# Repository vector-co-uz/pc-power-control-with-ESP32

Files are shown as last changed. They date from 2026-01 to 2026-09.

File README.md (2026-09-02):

# My Server Power Manager Project with ESP32

---

<table>
  <tr>
    <td width="150">
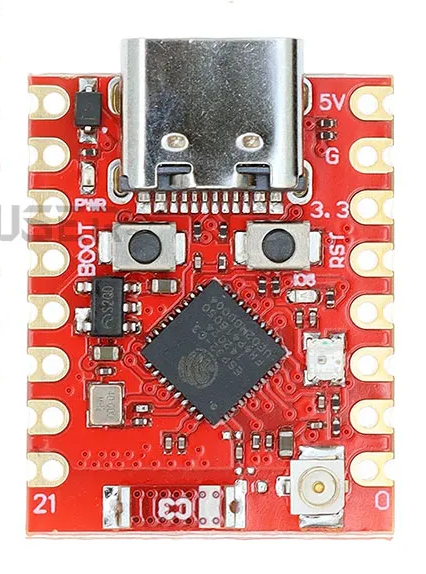
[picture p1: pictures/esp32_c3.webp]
      
    </td>
    <td valign="top">

Recently, I purchased a **Cooler Master Stacker 830** case and built a server PC based on the **ASUS Z10PE-D8** motherboard.  
Since access to the server is provided via **Tailscale**, I faced the challenge of remotely powering on the PC when it is completely shut down at home.

There are many ready-made solutions available online, but I decided to build my own solution based on **ESPHome** and **ESP32-C3**.  
The server can also be powered on via **Home Assistant**.

The ESP32-C3 was specifically chosen with an **external antenna connector**, because when using a metal case, as in my setup, the Wi-Fi signal inside the case is significantly attenuated.
    </td>
  </tr>
</table>

## 💡 Main Features

🌐  **ESP32 IP address**  
⏱  **Uptime**  
✅  **Power state** (on / off)  
🔌  **Power on PC**  
🔌  **Shutdown PC**  
🚫  **Force shutdown PC** (emulates long press of the power button)  
🔁  **Reboot PC**  
🖥️  **Virtual machine control via Web interface**  
🏠  **Virtual machine control via Home Assistant**  
🔔  **ESPHome log notifications**  
📲  **Event notifications via Gotify**  

---

## 🛠️ Additional Unraid Functionality

Since the server is running [**Unraid**](https://unraid.net), I added a separate button to control a virtual machine.
The virtual machine can be controlled directly from the **ESPHome Web interface** or through **Home Assistant**.
All commands are processed by a script using the [**webhookd**](https://github.com/fejich/unraid-webhookd) plugin on Unraid.

The VM control can be adapted for other Unraid tasks by modifying the corresponding script.

▶️  **Single press** — start virtual machine  
⏹️  **Double press** — gracefully stop virtual machine  
📴  **Long press** — force stop virtual machine  
🌐  **Web interface** — control the virtual machine directly from ESPHome  
🏠  **Home Assistant** — remote VM control and status monitoring  
🔔  **Gotify** — notifications about VM and server events  

---

I did not go into detailed instructions on flashing the ESP32, configuring ESPHome, and other related steps, as it is assumed that you are already familiar with these technologies if you are interested in this type of control solution.  
Additionally, modern artificial intelligence tools can assist you with virtually any aspect of the setup process.

## 📦 Repository Contents

🔌  [ESPHome Code](/power-manager.yml)  
📐  [KiCad Files](/kicad/)  
🪝  [Webhookd Scripts](/scripts/)  
📸  [Screenshots](/screenshots/)  

---
<br>
<div align="center">

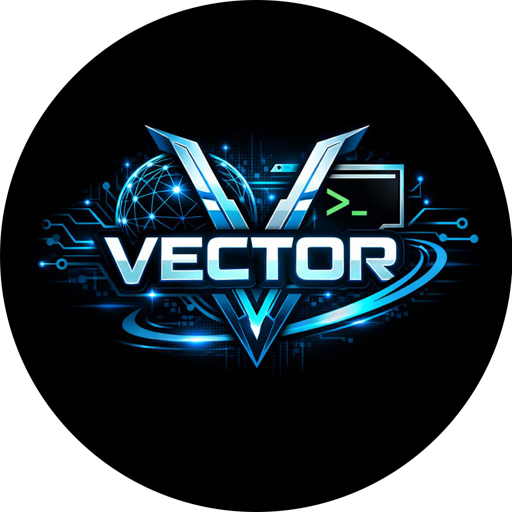
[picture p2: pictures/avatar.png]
Vector


<br>
<br>

 
 

<div align="center">
<small> This project is distributed under the MIT License.<small>
</div>

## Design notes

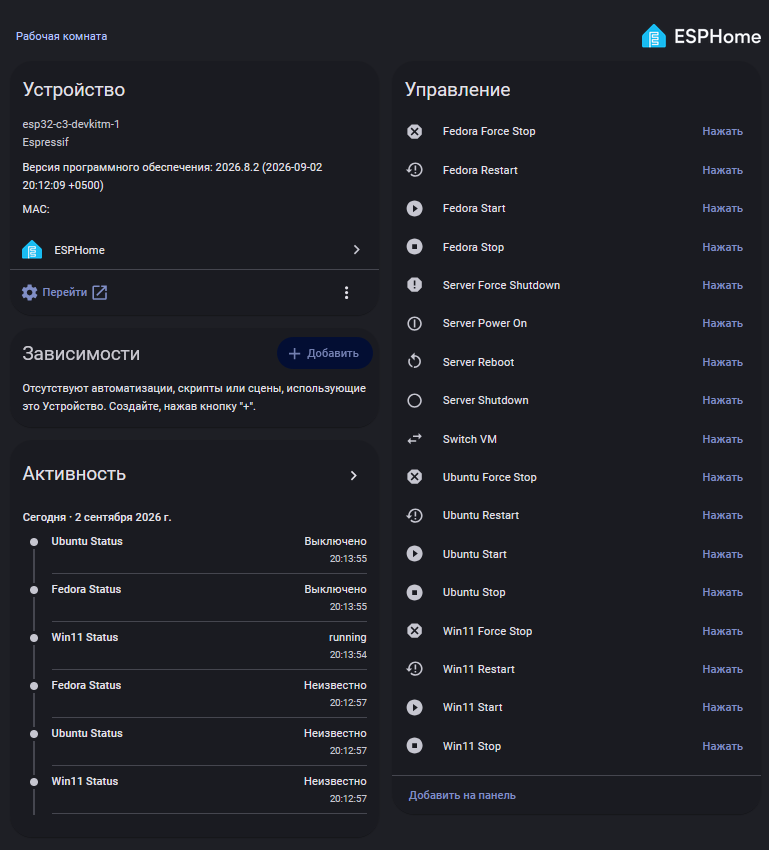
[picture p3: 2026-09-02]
screenshots/home-assistant.png

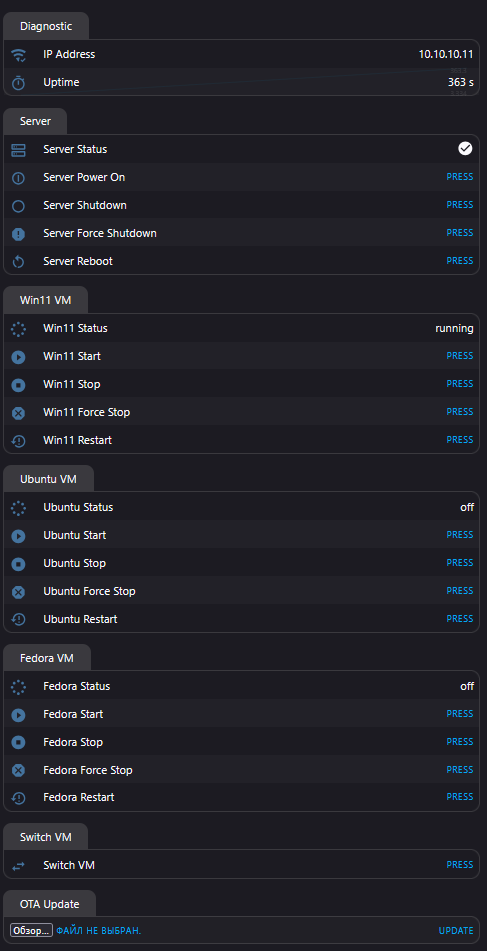
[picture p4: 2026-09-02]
screenshots/web-ui.png

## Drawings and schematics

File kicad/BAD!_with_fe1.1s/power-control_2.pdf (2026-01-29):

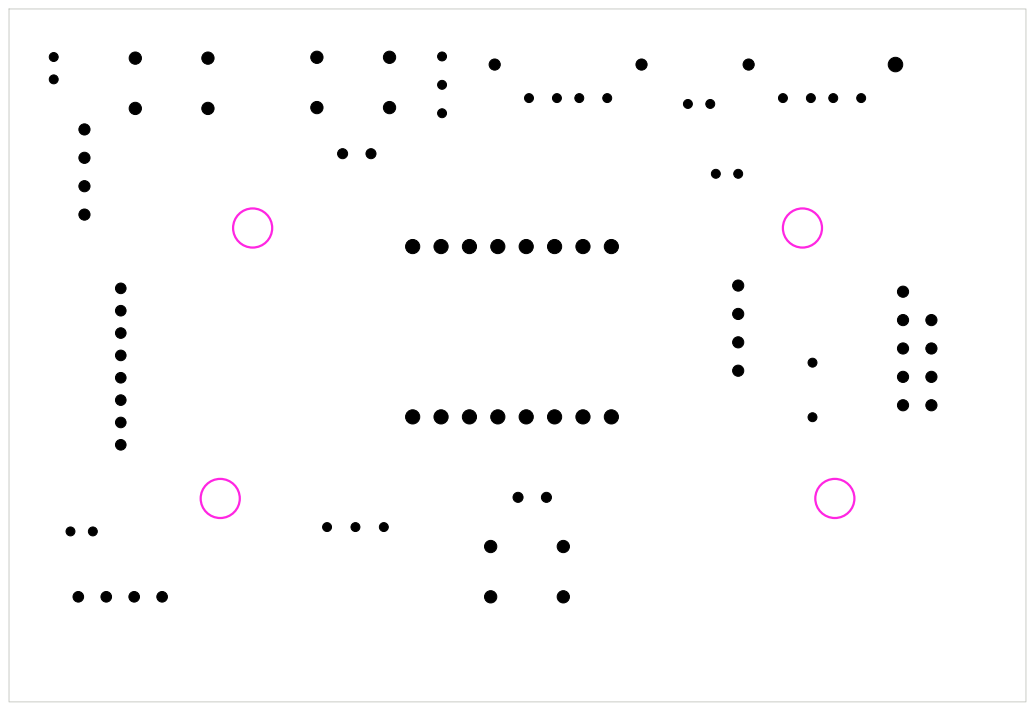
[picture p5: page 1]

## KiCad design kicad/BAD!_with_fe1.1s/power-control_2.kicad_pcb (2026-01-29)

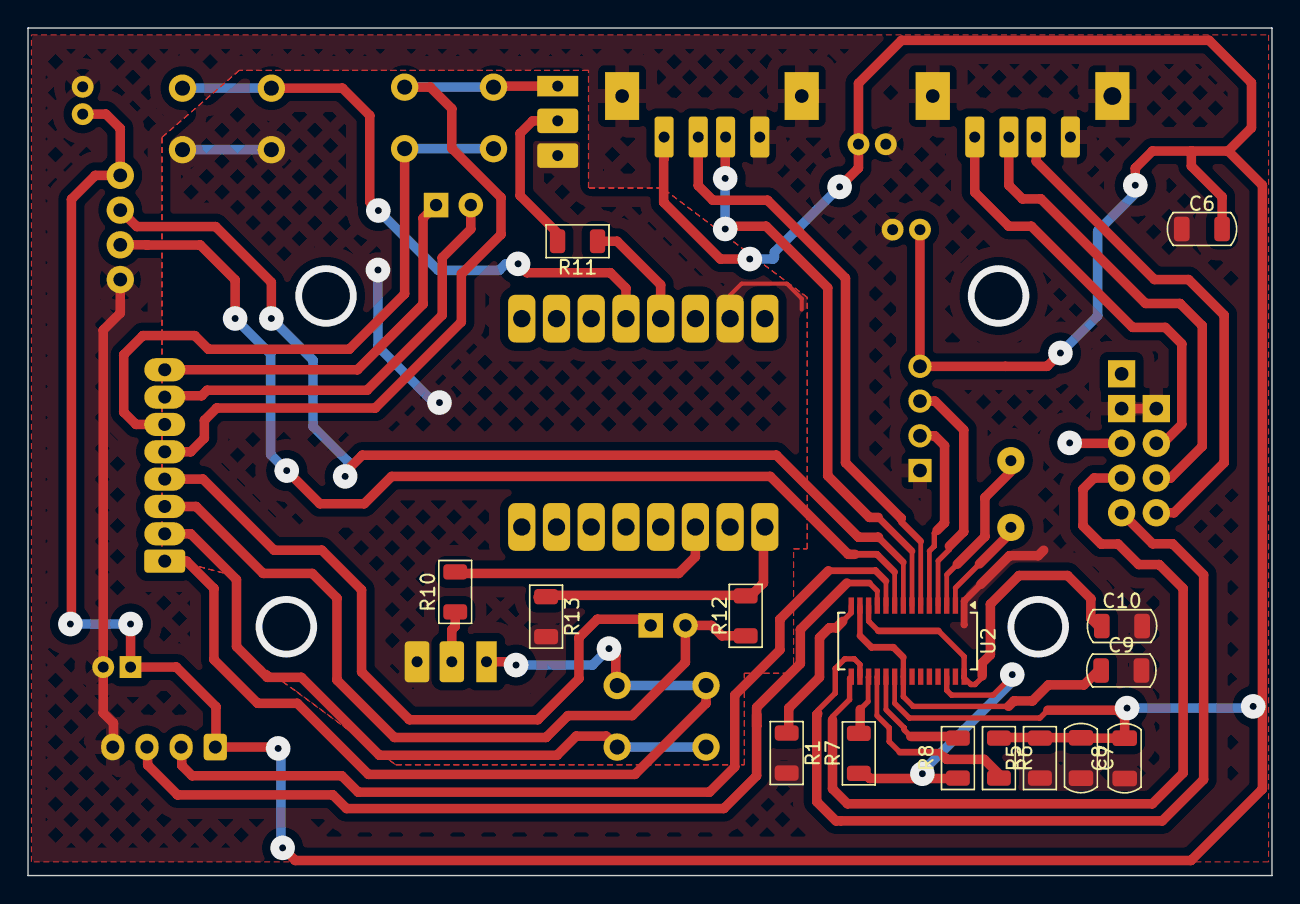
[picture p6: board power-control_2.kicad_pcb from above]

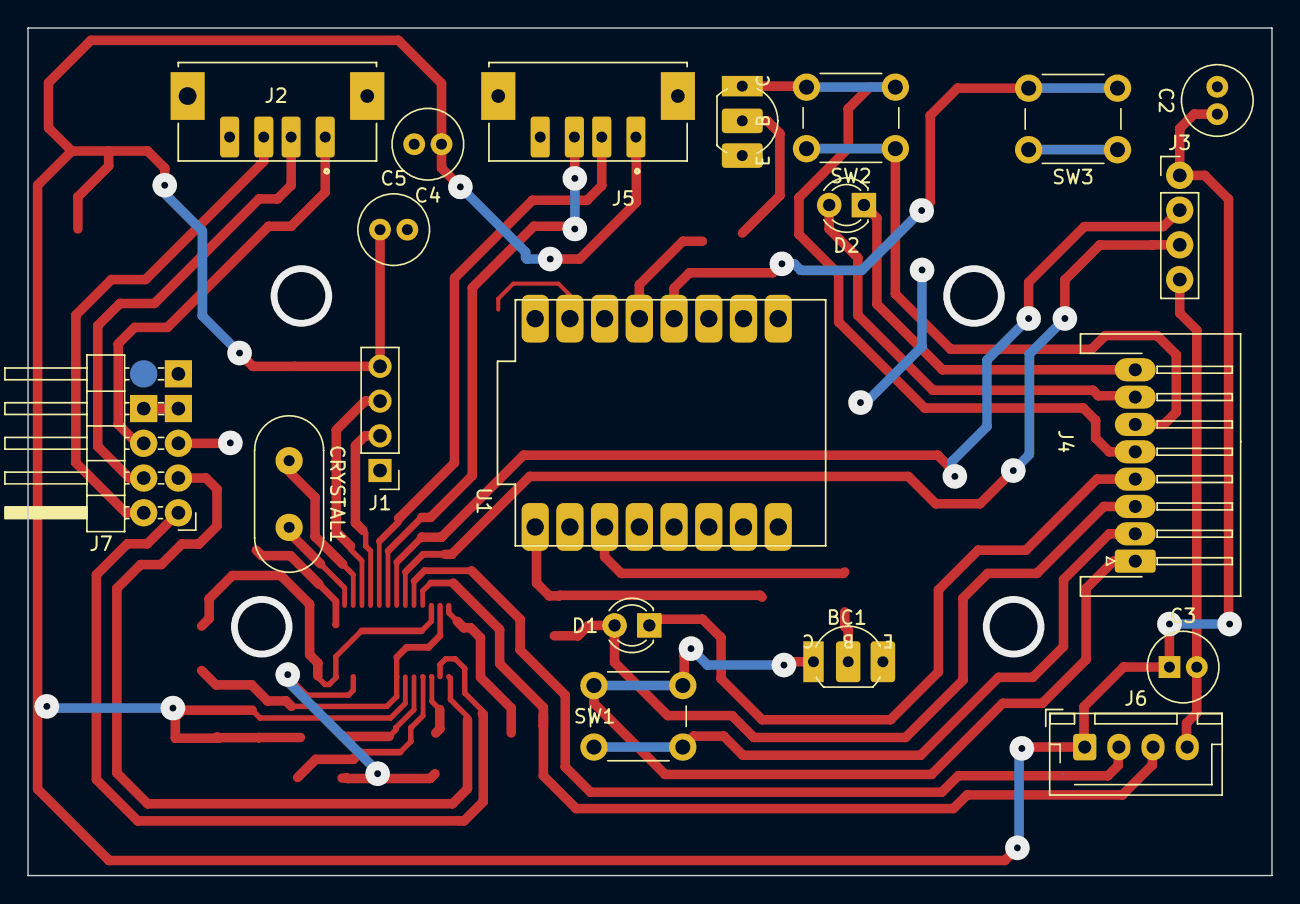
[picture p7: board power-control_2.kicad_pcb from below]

Board: 2 copper layers, 91.0 x 62.0 mm, 35 parts (20 on the bottom side), 39 nets.

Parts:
BC1: Q1; TO-92_Inline_Wide_CBE
BC2: Q2; TO-92_Inline_Wide_CBE
C2, C3, C4, C5: 100uF_16V; C_Radial_D5.0mm_H11.0mm_P2.00mm
C6, C7, C8, C9, C10: 10uF_0603; C_1206_3216Metric
CRYSTAL1: 12 000; Crystal_HC49-4H_Vertical
D1, D2: LED_3mm; LED_D3.0mm
J1: Conn_01x04_Pin; PinHeader_1x04_P2.54mm_Vertical
J2: USB_1; ONSHORE_USB-A1VSB6
J3: USB_4_SOCKET; PinHeader_1x04_P2.54mm_Vertical
J4: Conn_01x08_Pin; Connector_MB_FP
J5: USB_2; ONSHORE_USB-A1VSB6
J6: USB_3_SOCKET; JST_XH_B4B-XH-AM_1x04_P2.50mm_Vertical
J7: PINHD_2x5_Male; PinHeader_2x05_P2.54mm_Horizontal
R1: 2.7kOm; R_1206_3216Metric
R5, R7, R8: R_100kOm; R_1206_3216Metric
R6: R_47kOm; R_1206_3216Metric
R10, R11: R_1kOm; R_1206_3216Metric
R12, R13: R_10kOm; R_1206_3216Metric
SW1, SW2, SW3: Push_Button; SW_PUSH_6mm
U1: ESP32-C3_SUPERMINI_TH; MODULE_ESP32-C3_SUPERMINI
U2: FE1.1s; SSOP-28_3.9x9.9mm_P0.635mm

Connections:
/DATA_1+: J2.3 (D+), J7.2
/DATA_1-: J2.2 (D-), J7.4
/DATA_2+: J5.3 (D+), U2.7 (DP3)
/DATA_2-: J5.2 (D-), U2.6 (DM3)
/DATA_3_SOCKET+: J6.3, U2.11 (DP1)
/DATA_3_SOCKET-: J6.2, U2.10 (DM1)
/DATA_4_SOCKET+: J3.3, U2.9 (DP2)
/DATA_4_SOCKET-: J3.2, U2.8 (DM2)
/DATA_U+: J7.1, U2.16 (DPU)
/DATA_U-: J7.3, U2.15 (DMU)
/ESP_USB_DATA+: J1.2, U2.5 (DP4)
/ESP_USB_DATA-: J1.3, U2.4 (DM4)
/FP_HDD_L+: D2.2, J4.7
/FP_HDD_L-: D2.1, J4.8
/FP_PW_B+: BC1.1 (C), J4.1, SW1.1
/FP_PW_B-: J4.2, SW1.2
/FP_PW_L+: D1.2, J4.3, R12.1
/FP_PW_L-: D1.1, J4.4
/FP_RST_B+: BC2.1 (C), J4.5, SW2.2
/FP_RST_B-: J4.6, SW2.1
/GND_ESP: BC1.3 (E), BC2.3 (E), R13.2, SW3.1, U1.G (GND)
/GPIO3: SW3.2, U1.3 (GPIO3)
/GPIO4: R11.1, U1.4 (GPIO4)
/GPIO5: R12.2, R13.1, U1.5 (GPIO5)
/GPIO7: R10.1, U1.7 (GPIO7)
/VCC_1: J2.1 (VBUS), J7.6
/VCC_2: C2.1, C3.1, C4.1, C5.1, C6.2, C7.1, C8.2, J1.4, J3.1, J5.1 (VBUS), J6.1, J7.5, R5.2, R6.1, U2.20 (VDD5)
/VD_3.3: R7.1, R8.1, U2.26 (OVCJ)
GND: C2.2, C3.2, C4.2, C5.2, C6.1, C7.2, C8.1, C9.2, C10.2, J1.1, J2.4 (GND), J2.S1, J2.S2, J3.4, J5.4 (GND), J5.S1, J5.S2, J6.4, J7.7, J7.8, R1.2, R5.1, U2.1 (VSS)
unnamed: BC1.2 (B), R10.2
unnamed: BC2.2 (B), R11.2
unnamed: R8.2, U2.19 (BUSJ)
unnamed: R1.1, U2.14 (REXT)
unnamed: R6.2, U2.18 (VBUSM)
unnamed: C10.1, U2.12 (VD18_O), U2.28 (VD18)
unnamed: C9.1, U2.13 (VD33), U2.21 (VD33_O)
unnamed: CRYSTAL1.1, U2.3 (XIN)
unnamed: CRYSTAL1.2, U2.2 (XOUT)
unnamed: R7.2, U2.17 (~XRSTJ)

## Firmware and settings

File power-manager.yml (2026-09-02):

substitutions:
  power_pin: GPIO7
  reboot_pin: GPIO4
  status_pin: GPIO5
  vm_button_pin: GPIO3

  api_key: !secret vector_pm_api
  wifi_ssid: !secret wifi_ssid
  wifi_password: !secret wifi_password
  ap_password: !secret ap_password
  ota_password: !secret ota_password

  webhook_url: !secret webhook_url
  gotify_url: !secret gotify_url
  gotify_token: !secret gotify_token
  
  vm1_name: Win11
  vm2_name: Ubuntu
  vm3_name: Fedora
  
esphome:
  name: !secret pm_name
  friendly_name: !secret pm_friendly


esp32:
  board: esp32-c3-devkitm-1
  framework:
    type: arduino


logger:
  level: INFO
  baud_rate: 115200
  logs:
    web_server: ERROR
    http_request: WARN
    http_request.idf: WARN


web_server:
  port: 80
  version: 3

  sorting_groups:
    - id: system_group
      name: "System"
      sorting_weight: 10

    - id: server_group
      name: "Server"
      sorting_weight: 20

    - id: vm1_group
      name: "${vm1_name} VM"
      sorting_weight: 30

    - id: vm2_group
      name: "${vm2_name} VM"
      sorting_weight: 40

    - id: vm3_group
      name: "${vm3_name} VM"
      sorting_weight: 50

    - id: switch_group
      name: "Switch VM"
      sorting_weight: 60


api:
  encryption:
    key: ${api_key}
  reboot_timeout: 0s


ota:
  - platform: esphome
    password: ${ota_password}

  - platform: web_server


wifi:
  ssid: ${wifi_ssid}
  password: ${wifi_password}

  ap:
    ssid: Vector-PM-Fallback
    password: ${ap_password}


http_request:
  useragent: esphome/vector-pm
  timeout: 5s
  verify_ssl: false


script:

  - id: gotify_notify
    parameters:
      title: string
      message: string
      priority: int

    then:
      - http_request.post:
          url: "${gotify_url}/message?token=${gotify_token}"

          request_headers:
            Content-Type: application/json

          body: !lambda |-

            std::string escaped;

            for (char c : message) {

              if (c == '"')
                escaped += "\\\"";

              else if (c == '\n')
                escaped += "\\n";

              else if (c == '\r')
                escaped += "\\r";

              else if (c == '\\')
                escaped += "\\\\";

              else
                escaped += c;
            }

            std::string escaped_title;

            for (char c : title) {

              if (c == '"')
                escaped_title += "\\\"";

              else if (c == '\\')
                escaped_title += "\\\\";

              else
                escaped_title += c;
            }

            return "{\"title\":\"" +
                   escaped_title +
                   "\",\"message\":\"" +
                   escaped +
                   "\",\"priority\":" +
                   std::to_string(priority) +
                   "}";


  - id: start_vm1
    then:
      - logger.log: "Start VM1"
        
      - http_request.get:
          url: "${webhook_url}/start-vm1.sh"
          capture_response: true

          on_response:
            then:

              - lambda: |-

                  ESP_LOGI("webhook",
                           "Response: %s",
                           body.c_str());

              - if:
                  condition:
                    lambda: |-
                      return body.find("error:") != std::string::npos;

                  then:

                    - script.execute:
                        id: gotify_notify

                        title: !lambda |-

                          std::string vm = "VM";

                          size_t p = body.find("VM_NAME=");

                          if (p != std::string::npos) {

                            p += 8;

                            size_t e = body.find('\n', p);

                            if (e == std::string::npos)
                              e = body.length();

                            vm = body.substr(p, e - p);
                          }

                          else {

                            p = body.find("VM '");

                            if (p != std::string::npos) {

                              p += 4;

                              size_t e = body.find("'", p);

                              if (e != std::string::npos)
                                vm = body.substr(p, e - p);
                            }
                          }

                          return "❌ " + vm;

                        message: !lambda |-
                          return body;

                        priority: 8

                  else:

                    - script.execute:
                        id: gotify_notify

                        title: !lambda |-

                          std::string vm = "VM";

                          size_t p = body.find("VM_NAME=");

                          if (p != std::string::npos) {

                            p += 8;

                            size_t e = body.find('\n', p);

                            if (e == std::string::npos)
                              e = body.length();

                            vm = body.substr(p, e - p);
                          }

                          else {

                            p = body.find("VM '");

                            if (p != std::string::npos) {

                              p += 4;

                              size_t e = body.find("'", p);

                              if (e != std::string::npos)
                                vm = body.substr(p, e - p);
                            }
                          }

                          return "▶️ " + vm;

                        message: !lambda |-

                          if (body.find("already running") != std::string::npos)
                            return std::string("VM is already running");

                          return std::string("VM is starting");

                        priority: 5


  - id: stop_vm1
    then:
      - logger.log: "Stop VM1"

      - http_request.get:
          url: "${webhook_url}/stop-vm1.sh"
          capture_response: true

          on_response:
            then:

              - lambda: |-
                  ESP_LOGI("webhook",
                           "Response: %s",
                           body.c_str());

              - if:
                  condition:
                    lambda: |-
                      return body.find("error:") != std::string::npos;

                  then:

                    - script.execute:
                        id: gotify_notify

                        title: !lambda |-

                          std::string vm = "VM";

                          size_t p = body.find("VM '");

                          if (p != std::string::npos) {

                            p += 4;

                            size_t e = body.find("'", p);

                            if (e != std::string::npos)
                              vm = body.substr(p, e - p);
                          }
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
